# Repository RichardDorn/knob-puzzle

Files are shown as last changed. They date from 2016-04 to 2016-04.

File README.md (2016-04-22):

# Knob Puzzle

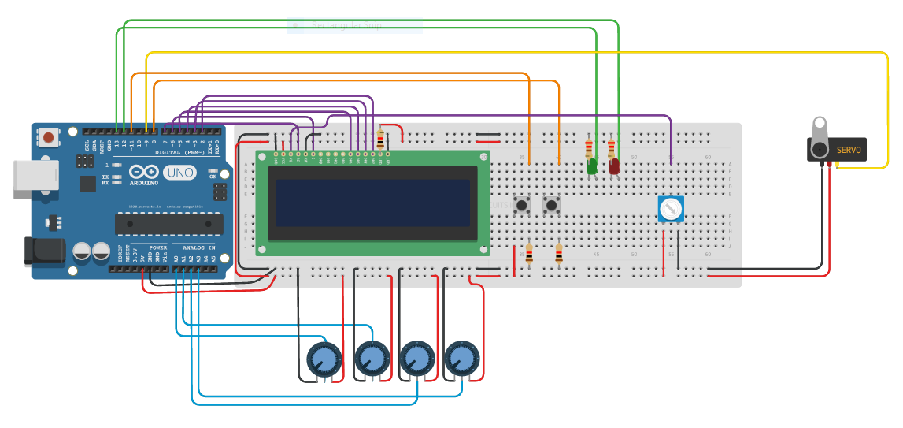
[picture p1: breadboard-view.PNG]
Breadboard-View Schematic

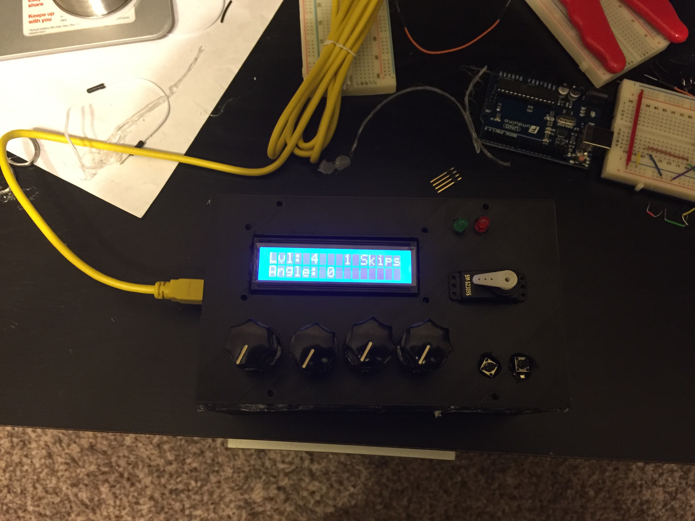
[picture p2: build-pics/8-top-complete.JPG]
Top Finsihed Knob Puzzle

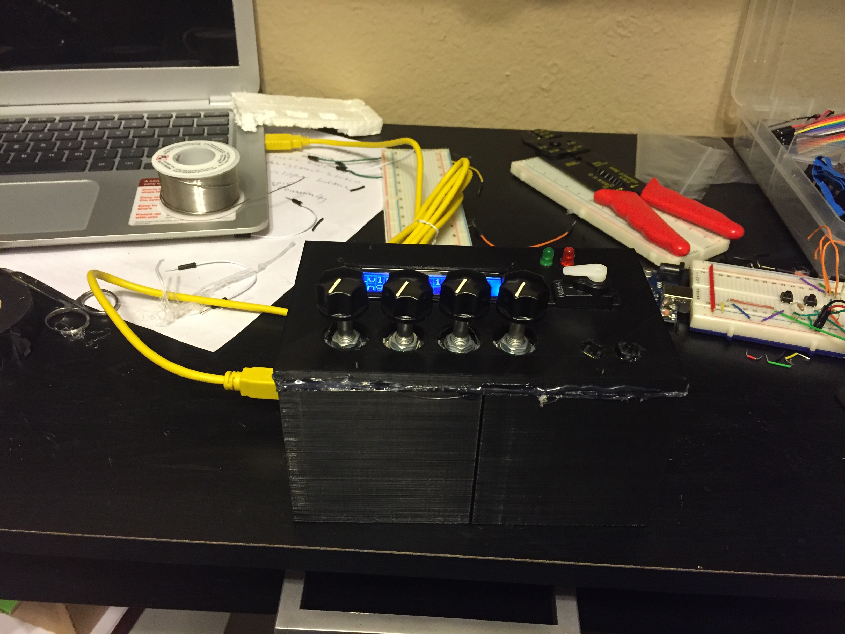
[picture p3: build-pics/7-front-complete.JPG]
Front Finished Knob Puzzle


This is my first arduino build outside of the starter kit and my first real attempt at coding in general. It is a puzzle game in which players must figure out the relationship between 4 knobs to move a single servo 180 degrees from left to right with the aid of an lcd displaying the current angle.

The game can be played in Campaign Mode or Random Mode. Campaign consists of 10 levels and an "easter egg" to access the credits after beating the final level. Random not only randomizes the level order but also the knob assignment within each level.
**I have tried to document the source code as clearly as possible. Most functionality questions are answered there.**

The plastic components were designed in tinkercad and printed on a friend's DaVinci Jr. The finished product is 6" x 3.5" x 4". Total print time was 55-60 hours. [Box](https://www.tinkercad.com/things/bzaXPIe8NDD-box/edit), [Lid](https://www.tinkercad.com/things/7vqB7K1yFgU-lid/edit), [Pot Mounts](https://www.tinkercad.com/things/hdNZIUxdLzm-pot-mounts/edit)

Putting everything together proved to be more difficult than I expected mainly because I didn't solder every connection. It was difficult to stuff the 22AWG wire inside without dislodging some of the breadboard connections. I had originally planned to screw the lid on but didn't have the hardware when I started building. After the frustration of making everything fit I just hot glued it on.

I think it still came out nice. It feels sturdy, has nice weight to it and the visibile glue doesn't really detract too much.

## This repository includes:
  * Source Code
  * Breadboard-View Schematic
  * Pictures of the build process
  * .stl files for 3d printing the box, lid and potentiometer mounts

## Coming Soon:
  * I'll try to get a good video playthrough made

## Components List:
  * 1 x Arduino Uno (Chinese clone ~$2.60)
  * 2 x 170 tie-point mini-breadboards (~$0.75)
  * ~90 meters x XYZ Printing DaVinci Jr. PLA filament ($12.60)
  * 1 x 16x2 LCD display (eBay ~$2.50)
  * 1 x 9g servo motor (The one that comes with arduino starter kit)
  * 2 x LEDs: 1 green, 1 red
  * 2 x momentary switches
  * 4 x 16mm 10K-ohm linear potentiometers (~$8)
  * 1 x small 10K-ohm linear potentiometer (Came with starter kit. Used here to control contrast of lcd.)
  * 4 x 19mm plastic knob covers (~$8)
  * 5 x resistors: 3 220-ohm, 2 10K-ohm
  * Various wire and jumpers
  * * I also bought a nice adaptor that fits between a wall wart and arduino to give it a nice on/off switch for about $2. (Not pictured above.)

## Room for improvement:
  * My measurements for all the components were a few mm off. This made it necessary to file the plastic down in many places in order to make things fit. I suggest measuring your own components and adjusting the .stl files accordingly.
  
  * Due to time limitations on the available printer the box had to be split into 2 prints then glued together. The fit is less than perfect. I left the unsplit box in the box.stl file incase print time isn't an issue.
 
  * A big improvement to the UX could be made by redesigning the box with the potentiometers mounted vertically out of the face of the box. If you're a lefty its no big deal but for the majority who will manipulate the knobs with their right hand, the servo becomes difficult to see.
 
  * Similar improvement could be made to the lcd. You must be looking from a birds-eye view to see the screen. Mounting it with a slight tilt would make playing much more relaxing.
 
  * The code can still be streamlined with a little work. Currently the levels are written twice... once for campaign and again for random mode.

  * Would be great to add sd functionality and easily switch between "level packs" rather than upload new code to arduino each time.

  * Using smaller 18AWG wire might make it easier to stuff inside the small box.

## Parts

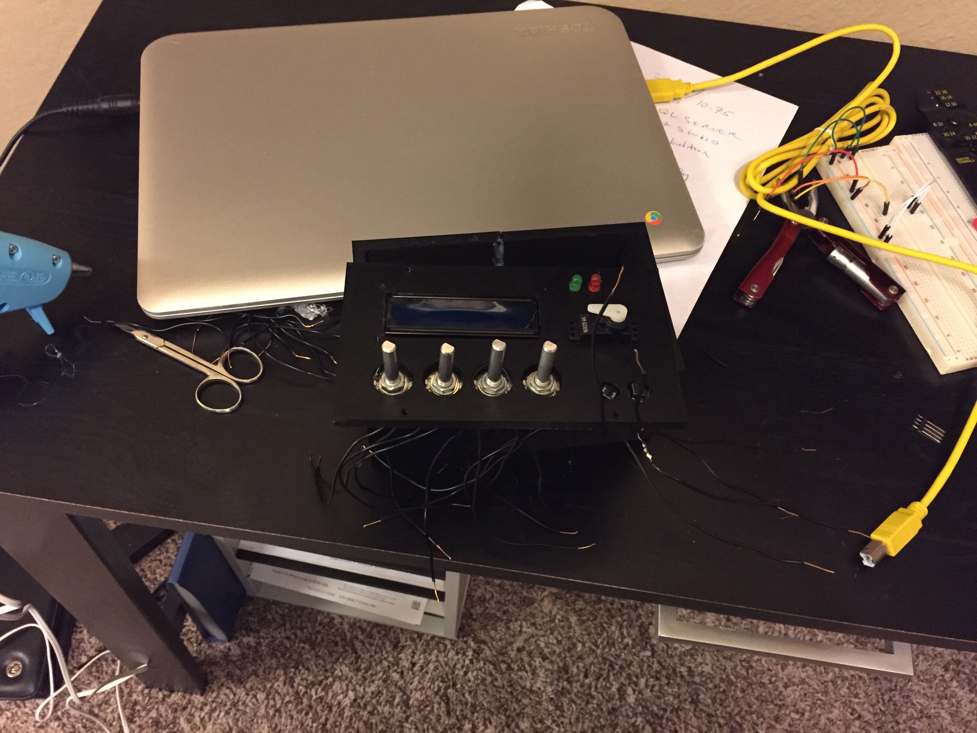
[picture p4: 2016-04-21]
build-pics/5-all-components.JPG

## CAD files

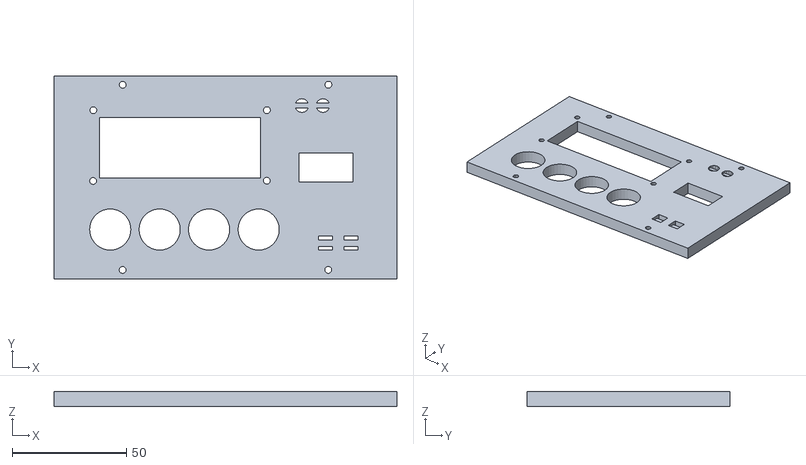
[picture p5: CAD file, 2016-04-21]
.stl-files/lid.stl
150.0 x 88.9 x 6.35

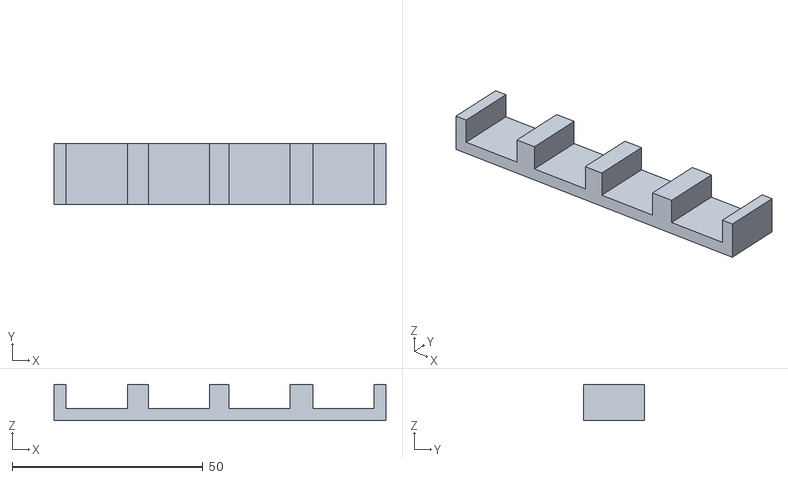
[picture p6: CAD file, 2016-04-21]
.stl-files/pot_mounts.stl
87.0 x 16.0 x 9.53

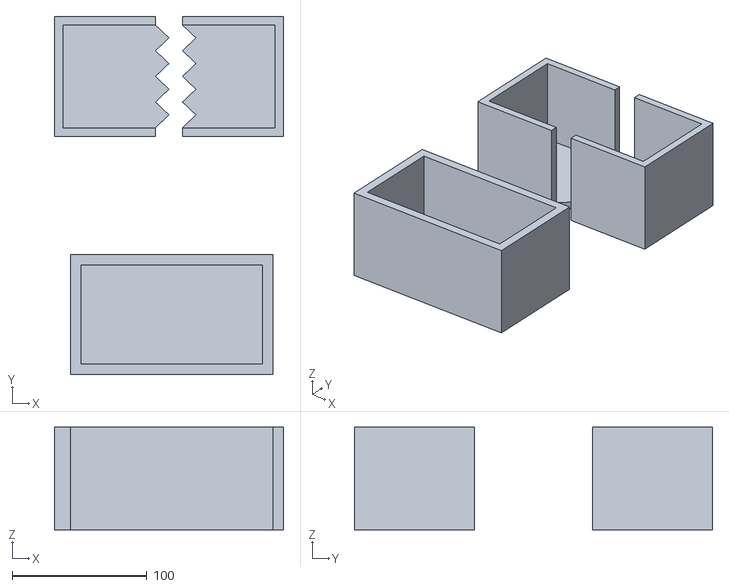
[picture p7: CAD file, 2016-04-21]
.stl-files/box.stl
170.0 x 265.5 x 76.2

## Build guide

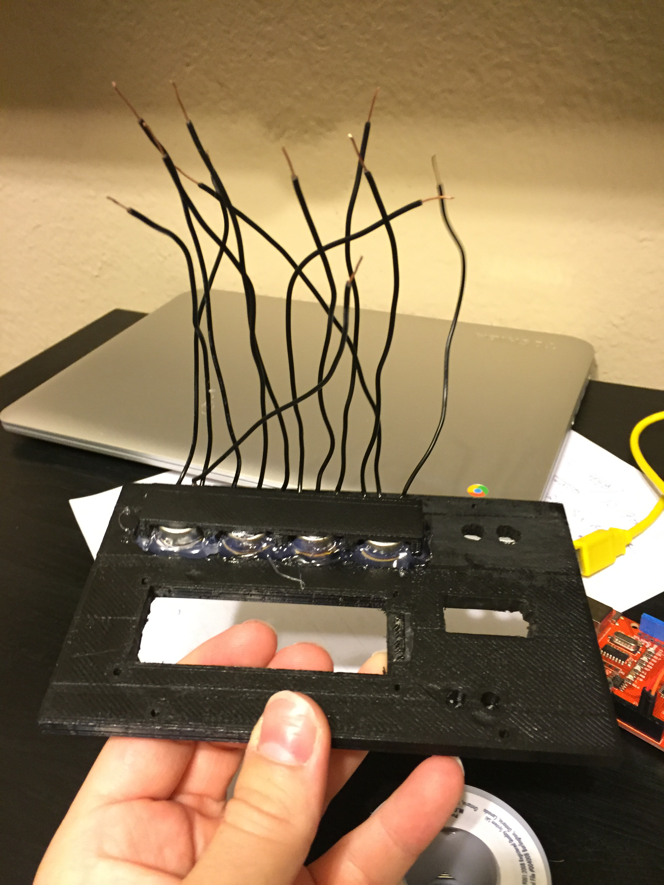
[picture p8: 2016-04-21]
build-pics/2-pot-mount.JPG

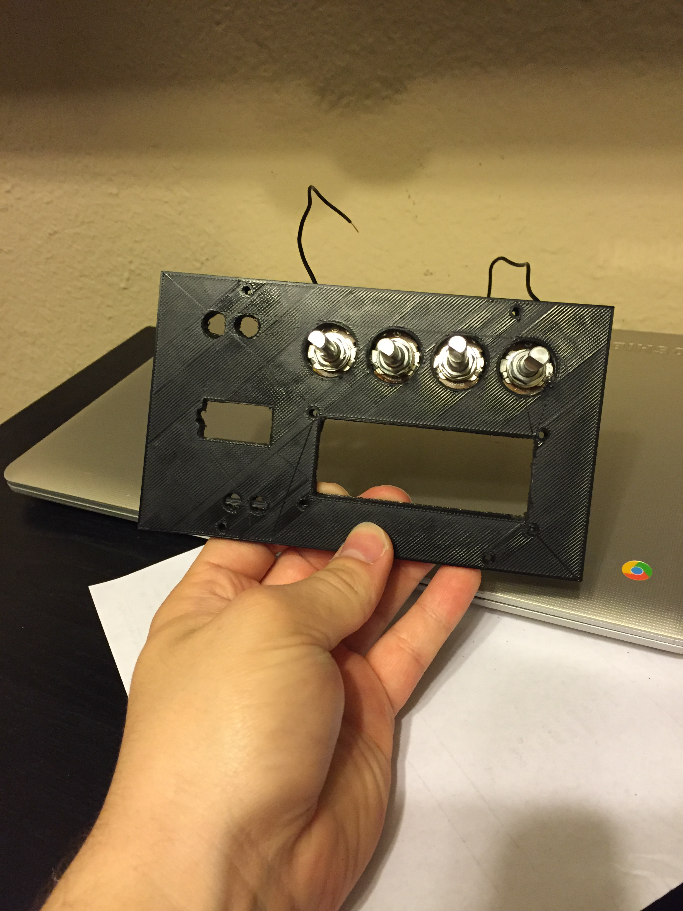
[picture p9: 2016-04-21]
build-pics/1-bare-potentiometers.JPG

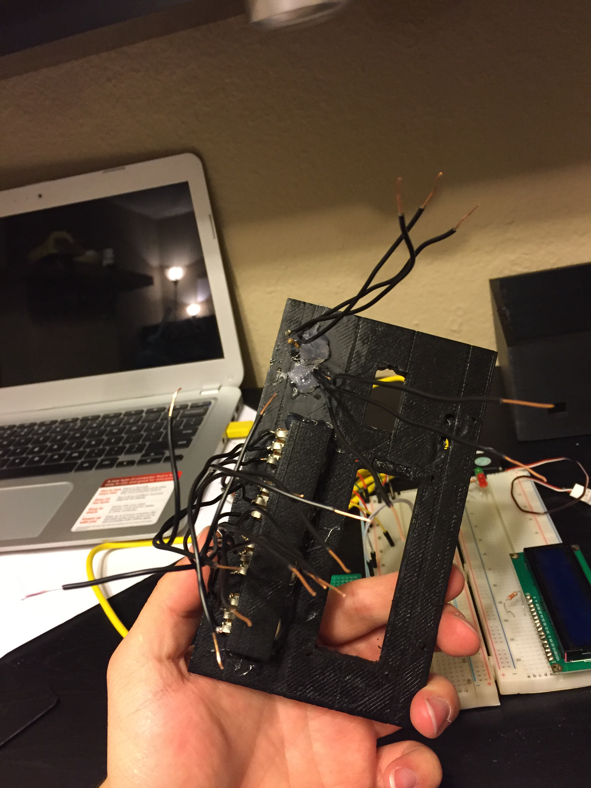
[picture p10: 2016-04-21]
build-pics/4-buttons-back.JPG

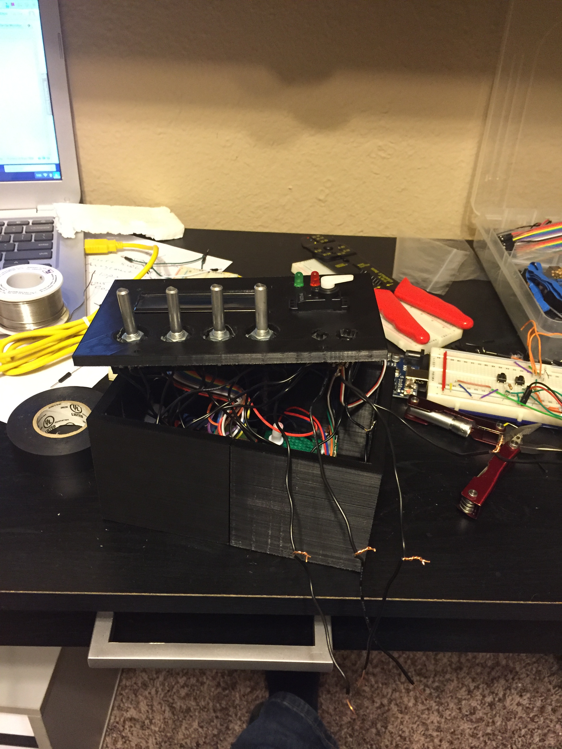
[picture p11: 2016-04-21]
build-pics/6-messy-wires.JPG

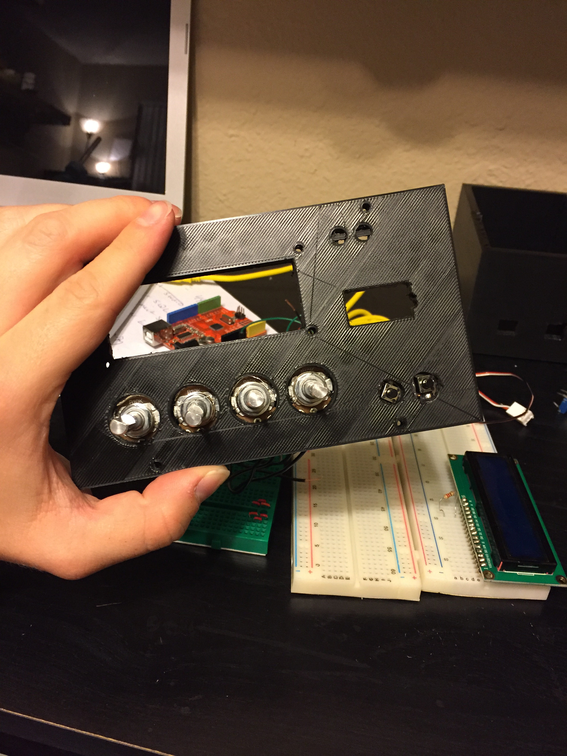
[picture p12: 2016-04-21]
build-pics/3-buttons-front.JPG

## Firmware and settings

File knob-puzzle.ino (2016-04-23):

#include <LiquidCrystal.h>
#include <Servo.h>
Servo myServo;
LiquidCrystal lcd(7, 6, 5, 4, 3, 2);	//(rs, enable, d4, d5, d6, d7)
const int potPin1 = A0;					//Input pins for potentiometers
const int potPin2 = A1;
const int potPin3 = A2;
const int potPin4 = A3;
const int skipPin = 11;					//Skip button pin
const int modePin = 8;					//Mode button pin
const int greenLedPin = 13;
const int redLedPin = 12;
int potVal1;			//Value of potentiometers 0-1023. Used to map(angle, ... 0, 179) and debounce pots.
int potVal2;
int potVal3;
int potVal4;
int skipState = 0;
int lastSkipState = 0;
int randState = 0;
int lastRandState = 0;
int randMode = 0;
int highestLevel = 10;	//****************************************************SET TO HIGHEST LEVEL**************************************************************
int randLevel = random(1, highestLevel+1);	//random() doesn't include the last value
int knobAssign = random(1, 5);	//Create switch(knobAssign) with 4 cases in each random level. Randomizes knob assignment in Random Mode
int angle;
int level = 1;		//Or whatever level you want to start on
int skips = 1;		//*******************************************************SET # OF SKIPS*********************************************************************
int begSkips = skips;		//Only need to adjust your starting skips once. (See lines 96, 117, 128) To change the amount of bonus skips in easter egg see last line of credits() function.
int passLevel = 0;			//Determines whether to continue playing a level or call nextLevel();
unsigned long startTime = 0;	//Time campaign mode started
long millis_held;				//Millis button has been pressed
long prevMillis_held;			//Used as comparison to check if button was released
unsigned long btnPressed;		//Time button was pressed
unsigned long currentTime;		//Time since campaign mode started


void setup() {
	pinMode(skipPin, INPUT);
	pinMode(modePin, INPUT);
	pinMode(greenLedPin, OUTPUT);
	pinMode(redLedPin, OUTPUT);
	myServo.attach(9);
	lcd.begin(16, 2);
	Serial.begin(9600);
	}


void loop() {
	currentTime = millis();
	potVal1 = analogRead(potPin1);
	potVal2 = analogRead(potPin2);
	potVal3 = analogRead(potPin3);
	potVal4 = analogRead(potPin4);
	skipState = digitalRead(skipPin);
	randState = digitalRead(modePin);
//////////////////////////////////////////////////////////////// SKIP Button /////////////////////////////////////////////////////////////////////////////
///////////////////////////////////////////////////////////////Easter Egg To Access Credits///////////////////////////////////////////////////////////////
	if(skipState == HIGH && lastSkipState == LOW){
		btnPressed = millis();				//If skip btn has just been pressed record the time
	}
	millis_held = millis() - btnPressed;	//Record how much time has passed since the button was pressed
	if(skipState == HIGH && millis_held > prevMillis_held && millis_held >= 5000 && level == highestLevel+1 && randMode == 0){
		level++;		//If the skip button has been held for 5 seconds and you've passed the final level... increase the level so campaign wont restart on button
		credits();		//release, then begin credits easter egg.
	}
	if(skipState == LOW && lastSkipState == HIGH){
		millis_held = 0;		//If the button has just been released reset millis_held
	}
	prevMillis_held = millis_held;
///////////////////////////////////////////////////////////////End Easter Egg///////////////////////////////////////////////////////////////////////////
	if(skipState != lastSkipState){
		if(skipState == HIGH && level < highestLevel && skips > 0){	//Skip Level
			lastSkipState = skipState;
			skips--;
			digitalWrite(redLedPin, HIGH);
			delay(30);
			digitalWrite(redLedPin, LOW);
			delay(30);
			digitalWrite(redLedPin, HIGH);
			delay(30);
			digitalWrite(redLedPin, LOW);
			delay(30);
			digitalWrite(redLedPin, HIGH);
			delay(30);
			digitalWrite(redLedPin, LOW);
			delay(30);
			passLevel = 1;
		}else if(randMode == 0 && skipState == HIGH && level == highestLevel){	//Block skip on final level
			lcd.clear();
			lcd.print("You May Not Skip");
			lcd.setCursor(0, 1);
			lcd.print("The Final Level!");
			delay(1500);
			lcd.clear();
		}else if(skipState == LOW && lastSkipState == HIGH && level == highestLevel+1){	//Restart campaign on button release after passing final level
			skips = begSkips;
			level = 1;
			startTime = currentTime;
			lcd.clear();
		}else if(skipState == HIGH && skips < 1 && level < highestLevel+1){	//Block skip if no skips remaining
			lcd.clear();
			lcd.print("No  Skips  Left.");
			lcd.setCursor(0, 1);
			lcd.print("   Good Luck.   ");
			digitalWrite(redLedPin, HIGH);
			delay(1500);
			lcd.clear();
			digitalWrite(redLedPin, LOW);
		}
	lastSkipState = skipState;
	}
///////////////////////////////////////////////////////////////////////////////MODE Button /////////////////////////////////////////////////////////	
	if(randState != lastRandState){
		if(randState == HIGH && randMode == 0){	//Enter Random Mode
			lastRandState = randState;
			level = 1;
			skips = begSkips;
			lcd.setCursor(0, 0);
			lcd.write("    Entering    ");
			lcd.setCursor(0, 1);
			lcd.write("  Random  Mode  ");
			delay(2000);
			randMode = !randMode;
			
		}else if(randState == HIGH && randMode == 1){	//Enter Campaign Mode
			startTime = currentTime;
			level = 1;
			skips = begSkips;
			lcd.setCursor(0, 0);
			lcd.write("    Entering    ");
			lcd.setCursor(0, 1);
			lcd.write(" Campaign  Mode ");
			delay(2000);
			randMode = !randMode;
		}
		lastRandState = randState;
	}
//////////////////////////////////////////////////////////////////// Campaign Mode //////////////////////////////////////////////////////////////////////
	if(randMode == 0 && passLevel == 0){
		stats();	//Display current level and remaining skips
		switch(level){
			
			case 1:{												//Level 1
					angle = map(potVal3, 0, 1023, 0, 179);		//Pretty simple. Knob 3 moves the servo 180 deg. using the potentiometer's full range of motion.
					myServo.write(angle);
				}
			break;
			//////////////////////////////////////////////////////////////////////////////////////////////////////////////////////////////////////
			case 2:{												//Level 2
					if(potVal1 >= 1020){						//If knob 1 is very close to max, knob 4 will run all the way to 179.
						angle = map(potVal4, 0, 1023, 0, 179);		
						myServo.write(angle);
					}
			break;
			}
			//////////////////////////////////////////////////////////////////////////////////////////////////////////////////////////////////////
			case 3:{												//Level 3
					int pot1 = map(potVal1, 0, 1023, 0, 179);		//The extra variables made it easier to write the if statements below without affecting angle	
					int pot2 = map(potVal2, 0, 1023, 0, 179);
					int pot3 = map(potVal3, 0, 1023, 0, 179);
					int pot4 = map(potVal4, 0, 1023, 0, 179);
					angle = pot1 + pot2 + pot3 + pot4;				//All it takes is adding the knobs together but...
					myServo.write(angle);
					if(pot1 > 45){									//If any of the knobs are turned past their 45 deg. allowance, servo resets.
						angle = 0;
						myServo.write(angle);
					}
					if(pot2 > 45){
						angle = 0;
						myServo.write(angle);
					}
					if(pot3 > 45){
						angle = 0;
						myServo.write(angle);
					}
					if(pot4 > 45){
						angle = 0;
						myServo.write(angle);
					}
			break;
			}
			//////////////////////////////////////////////////////////////////////////////////////////////////////////////////////////////////////
			case 4:{												//Level 4
					if(potVal1 <=3 && potVal3 <= 3 && potVal4 <= 3){		//If knob 1, 3 & 4 are low, 2 will run to 90 deg.	
						angle = map(potVal2, 0, 1023, 0, 90);
						myServo.write(angle);
					}
					if(potVal2 >= 1020 && potVal3 <= 3 && potVal4 <= 3){	//If knob 2 is all the way up while 3 and 4 are low, 1 will take it the rest of the way.
						angle = map(potVal1, 0, 1023, 90, 179);
						myServo.write(angle);
					}
			break;
			}
			//////////////////////////////////////////////////////////////////////////////////////////////////////////////////////////////////////
			case 5:{												//Level 5
					int firstHalf;														//If knob 2, 3 & 4 are low and 1 is max, servo will write 90.
					if(potVal2 <=3 && potVal3 <= 3 && potVal4 <= 3){		
						firstHalf = map(potVal1, 0, 1023, 0, 90);
					if(firstHalf == 90){												//Because there is nothing telling angle to change from 90 the servo will
						angle = 90;														//remain in place when knob 1 is turned down.
						myServo.write(angle);
					}
					}
					if(angle >= 88 && potVal1 <= 3 && potVal3 <= 3 && potVal2 <= 3){	//If angle is 90 and knob 1, 2 & 3 are low, 4 will take it the rest of the way.
						angle = map(potVal4, 0, 1023, 90, 179);
						myServo.write(angle);
					}
			break;
			}
			//////////////////////////////////////////////////////////////////////////////////////////////////////////////////////////////////////
			case 6:{												//Level 6
					int firstQuarter;													//This is the same logic as level 5. Only you must do it with all 4 knobs in ascending order.
					int secondQuarter;
					int thirdQuarter;
					int fourthQuarter;
					if(potVal2 <= 3 && potVal3 <= 3 && potVal4 <= 3){
						firstQuarter = map(potVal1, 0, 1023, 0, 45);
						if(firstQuarter == 45){
							angle = 45;
							myServo.write(angle);
						}
					}
					if(angle >= 43 && potVal1 <= 3 && potVal3 <= 3 && potVal4 <= 3){
						secondQuarter = map(potVal2, 0, 1023, 45, 90);
						if(secondQuarter == 90){
							angle = 90;
							myServo.write(angle);
						}
					}
					if(angle >= 88 && potVal1 <= 3 && potVal2 <= 3 && potVal4 <= 3){
						thirdQuarter = map(potVal3, 0, 1023, 90, 135);
						if(thirdQuarter == 135){
							angle = 135;
							myServo.write(angle);
						}
					}
					if(angle >= 133 && potVal1 <= 3 && potVal2 <= 3 && potVal3 <= 3){
						fourthQuarter = map(potVal4, 0, 1023, 135, 179);
						if(fourthQuarter == 179){
							angle = 179;
							myServo.write(angle);
						}
					}
			break;
			}
			//////////////////////////////////////////////////////////////////////////////////////////////////////////////////////////////////////
			case 7:{												//Level 7
					if(potVal1 <= 3 && potVal3 <= 3 && potVal4 <= 3){		//If all knobs are low 2 will take it just shy of winning.
						angle = map(potVal2, 0, 1023, 0, 178);
						myServo.write(angle);
					}
					if(potVal2 >= 1020 && potVal1 <= 3 && potVal4 <= 3){	//If 2 is max and 1 & 4 low, 3 will bring it back to zero.
						angle = map(potVal3, 0, 1023, 178, 0);
						myServo.write(angle);
					}
					if(potVal2 >= 1020 && potVal3 >= 1020 && potVal4 <= 3){		//If 2 & 3 max and 4 low, 1 will run all the way to 179.
						angle = map(potVal1, 0, 1023, 0, 179);
						myServo.write(angle);
					}
					if(angle == 179){
						extraSkip();										//This proved to be the first level players had a hard time with so to reward
					}														//those who do not skip it there is a bonus skip after completing the level.
			break;
			}
			//////////////////////////////////////////////////////////////////////////////////////////////////////////////////////////////////////
			case 8:{												//Level 8
					int key = map(potVal4, 0, 1023, 0, 135);									//Knob 1+2+3 = 135. If knob 4 is set to 45...
					int add3 = map(potVal3, 0, 1023, 0, 40);									//the other knobs will add onto it. Otherwise they are all limited.
					int add2 = map(potVal2, 0, 1023, 0, 60);
					int add1 = map(potVal1, 0, 1023, 0, 35);
					if(key >= 39 && key <= 45){
						angle = add1 + add2 + add3 + key;
						myServo.write(angle);
					}
					if(potVal3 <= 3 && potVal2 <= 3 && potVal1 <= 3 && key < 39 || key > 45){
						angle = key;
						myServo.write(angle);
					}
					if(potVal4 <=3 && potVal3 <=3 && potVal2 <= 3){
						angle = add1;
						myServo.write(angle);
					}
					if(potVal4 <=3 && potVal3 <=3 && potVal1 <= 3){
						angle = add2;
						myServo.write(angle);
					}
					if(potVal4 <=3 && potVal2 <=3 && potVal1 <= 3){
						angle = add3;
						myServo.write(angle);
					}
			break;
			}
			//////////////////////////////////////////////////////////////////////////////////////////////////////////////////////////////////////
			case 9:{												//Level 9
					if(potVal1 <= 3 && potVal2 <= 3 && potVal3 <=3 && potVal4 <= 3){		//The level begins with the servo one shy of winning.
						angle = 178;
						myServo.write(angle);
					}else if(potVal1 > 3 && potVal2 <= 3 && potVal3 <=3 && potVal4 <= 3){	//Each knob individually can run the servo back to zero.
						angle = map(potVal1, 0, 1023, 178, 0);
						myServo.write(angle);
					}else if(potVal2 > 3 && potVal1 <= 3 && potVal3 <=3 && potVal4 <= 3){
						angle = map(potVal2, 0, 1023, 178, 0);
						myServo.write(angle);
					}else if(potVal3 > 3 && potVal1 <= 3 && potVal2 <=3 && potVal4 <= 3){
						angle = map(potVal3, 0, 1023, 178, 0);
						myServo.write(angle);
					}else if(potVal4 > 3 && potVal1 <= 3 && potVal2 <=3 && potVal3 <= 3){	
						angle = map(potVal4, 0, 1023, 178, 0);
						myServo.write(angle);
					}else if(potVal2 >= 1020 && potVal1 <=3 && potVal3 <= 3){				//If knob 2 is max and 1 & 3 or low, 4 runs to 80 deg.
						angle = map(potVal4, 0, 1023, 0, 80);
						myServo.write(angle);
					}else if(potVal2 >= 1020 && potVal4 >= 1020 && potVal3 <= 3){			//If 2 & 4 max and 3 low, 1 runs to 160 deg.
						angle = map(potVal1, 0, 1023, 80, 160);
						myServo.write(angle);
					}else if(potVal2 >= 1020 && potVal4 >= 1020 && potVal1 >= 1020){		//If all others max, 3 runs to the end.
						angle = map(potVal3, 0, 1023, 160, 179);
						myServo.write(angle);
					}
			break;
			}
			//////////////////////////////////////////////////////////////////////////////////////////////////////////////////////////////////////
			case 10:{											//Level 10
					int add = map(potVal1, 0, 1023, 0, 135);										//Level begins with servo near winning again.	
					int sub1 = map(potVal2, 0, 1023, 0, 179);										//Sum of knob 2,3 & 4 subtracts from 178 bringing servo closer to 0.
					int sub2 = map(potVal3, 0, 1023, 0, 179);										//If any of those 3 goes beyond their limit, servo resets to 178.
					int sub3 = map(potVal4, 0, 1023, 0, 179);										//If all three are at their limit (178-45-45-43 = 45), knob 1 will
					if(potVal1 > 3 && potVal2 <= 3 && potVal3 <= 3 && potVal4 <= 3){				//add to the current angle. (45 + 135 = win!)
						angle = add;
						myServo.write(angle);
					}else if(potVal1 <= 3 && sub1 <= 45 && sub2 <= 45 && sub3 <= 43){
						angle = 178 - sub1 - sub2 - sub3;
						myServo.write(angle);
					}else if(sub1 > 45){
						angle = 178;
						myServo.write(angle);
					}else if(sub2 > 45){
						angle = 178;
						myServo.write(angle);
					}else if(sub3 > 43){
						angle = 178;
						myServo.write(angle);
					}else if(sub1 >= 40 && sub1 <= 45 && sub2 >= 40 && sub2 <= 45 && sub3 >= 40 && sub3 <= 43){
						angle = 178 - sub1 - sub2 - sub3 + add;
						myServo.write(angle);
					}
			break;
			}
			//////////////////////////////////////////////////////////////////////////////////////////////////////////////////////////////////////
		} //Close switch(level)
	} //close if(randMode == 0 && passLevel == 0)
///////////////////////////////////////////////////////////////////////////// Random Mode ////////////////////////////////////////////////////////////////
	else if(randMode == 1 && passLevel == 0){
		randStats();	//Display random mode and remaining skips
		switch(randLevel){
		
			case 1:{												//Level 1
					switch(knobAssign){
				
						case 1:{
							angle = map(potVal1, 0, 1023, 0, 179);
							myServo.write(angle);
						break;
						}
				///////////////////////////////////////////////////////////////////
						case 2:{
							angle = map(potVal2, 0, 1023, 0, 179);
							myServo.write(angle);
						break;
						}
				///////////////////////////////////////////////////////////////////
						case 3:{
							angle = map(potVal3, 0, 1023, 0, 179);
							myServo.write(angle);
						break;
						}
				///////////////////////////////////////////////////////////////////
						case 4:{
							angle = map(potVal4, 0, 1023, 0, 179);
							myServo.write(angle);
						break;
						}
				///////////////////////////////////////////////////////////////////
					}
			break;
			}
			//////////////////////////////////////////////////////////////////////////////////////////////////////////////////////////////////////
			case 2:{													//Level 2
					switch(knobAssign){
					
						case 1:{
							if(potVal1 >= 1020){
								angle = map(potVal4, 0, 1023, 0, 179);
								myServo.write(angle);
							}
						break;
						}
				///////////////////////////////////////////////////////////////////
						case 2:{
							if(potVal2 >= 1020){
								angle = map(potVal3, 0, 1023, 0, 179);
								myServo.write(angle);
							}
						break;
						}
				///////////////////////////////////////////////////////////////////	
						case 3:{
							if(potVal3 >= 1020){
								angle = map(potVal2, 0, 1023, 0, 179);
								myServo.write(angle);
							}
						break;
						}
				///////////////////////////////////////////////////////////////////	
						case 4:{
							if(potVal4 >= 1020){
								angle = map(potVal1, 0, 1023, 0, 179);
								myServo.write(angle);
							}
						break;
						}
				///////////////////////////////////////////////////////////////////		
					}
			break;
			}
		//////////////////////////////////////////////////////////////////////////////////////////////////////////////////////////////////////
			case 3:{														//Level 3
						//pots all go to 45 and add together in no particular order. No need for switch(knobAssign)
					int pot1 = map(potVal1, 0, 1023, 0, 179);
					int pot2 = map(potVal2, 0, 1023, 0, 179);
					int pot3 = map(potVal3, 0, 1023, 0, 179);
					int pot4 = map(potVal4, 0, 1023, 0, 179);
					angle = pot1 + pot2 + pot3 + pot4;
					myServo.write(angle);
					if(pot1 > 45){
						angle = 0;
						myServo.write(angle);
					}
					if(pot2 > 45){
						angle = 0;
						myServo.write(angle);
					}
					if(pot3 > 45){
						angle = 0;
						myServo.write(angle);
					}
					if(pot4 > 45){
						angle = 0;
						myServo.write(angle);
					}
			break;
			}
			//////////////////////////////////////////////////////////////////////////////////////////////////////////////////////////////////////
			case 4:{													//Level 4
					switch(knobAssign){
						
						case 1:{
							if(potVal1 <=3 && potVal3 <= 3 && potVal4 <= 3){
								angle = map(potVal2, 0, 1023, 0, 90);
								myServo.write(angle);
							}
							if(potVal2 >= 1020 && potVal3 <= 3 && potVal4 <= 3){
								angle = map(potVal1, 0, 1023, 90, 179);
								myServo.write(angle);
							}
						break;
						}
				///////////////////////////////////////////////////////////////////
						case 2:{
							if(potVal1 <=3 && potVal2 <= 3 && potVal3 <= 3){
								angle = map(potVal4, 0, 1023, 0, 90);
								myServo.write(angle);
							}
							if(potVal4 >= 1020 && potVal3 <= 3 && potVal1 <= 3){
								angle = map(potVal2, 0, 1023, 90, 179);
								myServo.write(angle);
							}
						break;
						}
				///////////////////////////////////////////////////////////////////
						case 3:{
							if(potVal1 <=3 && potVal2 <= 3 && potVal4 <= 3){
								angle = map(potVal3, 0, 1023, 0, 90);
								myServo.write(angle);
							}
							if(potVal3 >= 1020 && potVal1 <= 3 && potVal2 <= 3){
								angle = map(potVal4, 0, 1023, 90, 179);
								myServo.write(angle);
							}
						break;
						}
				///////////////////////////////////////////////////////////////////
						case 4:{
							if(potVal2 <=3 && potVal3 <= 3 && potVal4 <= 3){
								angle = map(potVal1, 0, 1023, 0, 90);
								myServo.write(angle);
							}
							if(potVal1 >= 1020 && potVal2 <= 3 && potVal4 <= 3){
								angle = map(potVal3, 0, 1023, 90, 179);
								myServo.write(angle);
							}
						break;
						}
				///////////////////////////////////////////////////////////////////
					}
			break;
			}
			case 5:{														//Level 5
					int firstHalf;
					switch(knobAssign){
						
						case 1:{
							if(potVal2 <=3 && potVal3 <= 3 && potVal4 <= 3){
								firstHalf = map(potVal1, 0, 1023, 0, 90);
								if(firstHalf == 90){
									angle = 90;
									myServo.write(angle);
								}
							}
							if(angle >= 88 && potVal1 <= 3 && potVal2 <= 3 && potVal3 <= 3){
								angle = map(potVal4, 0, 1023, 90, 179);
								myServo.write(angle);
							}
						break;
						}
				///////////////////////////////////////////////////////////////////
						case 2:{
							if(potVal1 <=3 && potVal2 <= 3 && potVal4 <= 3){
								firstHalf = map(potVal3, 0, 1023, 0, 90);
								if(firstHalf == 90){
									angle = 90;
									myServo.write(angle);
								}
							}
							if(angle >= 88 && potVal2 <= 3 && potVal3 <= 3 && potVal4 <= 3){
								angle = map(potVal1, 0, 1023, 90, 179);
								myServo.write(angle);
							}
						break;
						}
				///////////////////////////////////////////////////////////////////
						case 3:{
							if(potVal1 <=3 && potVal3 <= 3 && potVal4 <= 3){
								firstHalf = map(potVal2, 0, 1023, 0, 90);
								if(firstHalf == 90){
									angle = 90;
									myServo.write(angle);
								}
							}
							if(angle >= 88 && potVal1 <= 3 && potVal2 <= 3 && potVal4 <= 3){
								angle = map(potVal3, 0, 1023, 90, 179);
								myServo.write(angle);
							}
						break;
						}
				///////////////////////////////////////////////////////////////////
						case 4:{
							if(potVal1 <=3 && potVal2 <= 3 && potVal3 <= 3){
								firstHalf = map(potVal4, 0, 1023, 0, 90);
								if(firstHalf == 90){
									angle = 90;
									myServo.write(angle);
								}
							}
							if(angle >= 88 && potVal1 <= 3 && potVal3 <= 3 && potVal4 <= 3){
								angle = map(potVal2, 0, 1023, 90, 179);
								myServo.write(angle);
							}
						break;
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
